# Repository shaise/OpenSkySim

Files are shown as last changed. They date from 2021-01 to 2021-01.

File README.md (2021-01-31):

# OpenSkySim
A wireless rc simulator controller

## Description
This open project aims to develop a small USB dongle that lets you use your FrSky transmitter as an RC simulator controller wirelessly. You only need to bind your transmitter to the dongle and start playing!  
This dongle supports both standard HID compatible simulators, AND PhoenixRC!  
The hardware is bases on STM32F103 microcontroller and TI CC2500 transceiver. The firmware is based on OpenSky FrSky-compatible receiver: https://github.com/fishpepper/OpenSky

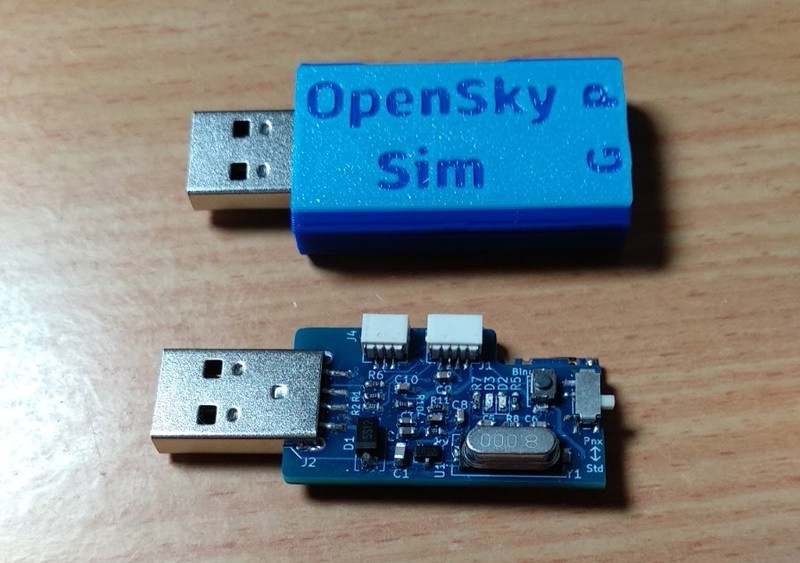
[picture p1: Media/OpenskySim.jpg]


## Assembling instructions

* Order the PCB by sending the [gerber files ](/Release/gerbers_frsim_2Layer_FR4.zip) to a manufacturer of your choice. I recommend [JLCPCB](https://jlcpcb.com/).
* Order all parts as listed in the [BOM](/Release/OpenSkySimBom.pdf) file. You will need a 0603 kit of resistors and capacitors, and for all other parts you will find a link in the BOM.
* Solder all parts. You can use the [Interactive BOM](https://htmlpreview.github.io/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) to assist you. 
* For the transmitter module, I used one without built in antenna, So if you are using the same module, you will need to add an antenna by soldering a 0.5mm transformer wire to the antenna pin, then trim the wire to a length of 31.5mm. (I tried one module with on board antenna but the reception was bad, If you find one that works, please let me know). Plese note: there are parts on both side of the PC
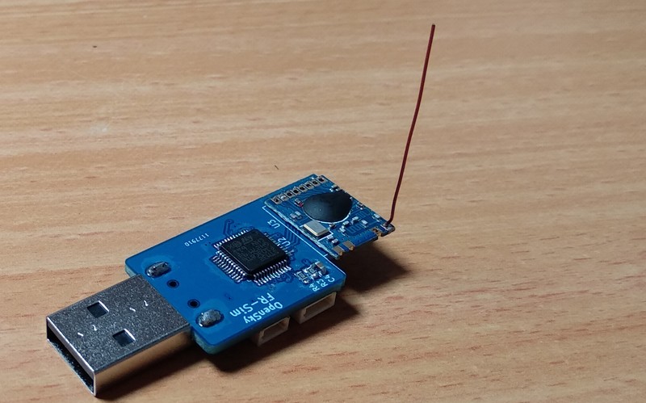
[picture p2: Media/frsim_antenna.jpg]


Top Side (click to enlarge):  
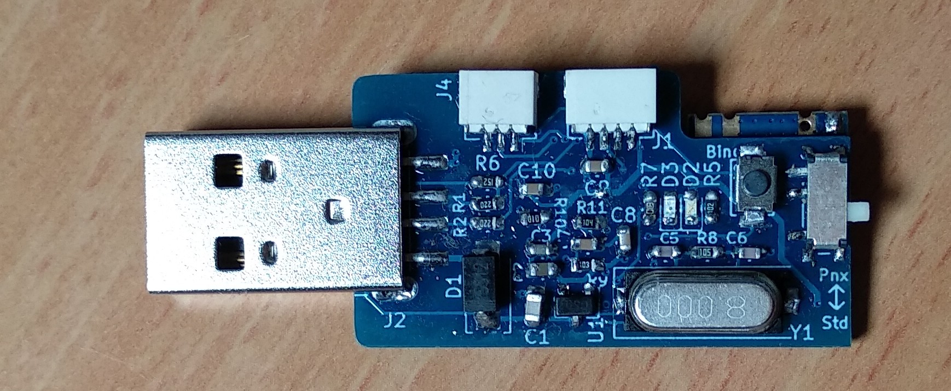
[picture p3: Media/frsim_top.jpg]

* If you have an access to a 3D printer you can print a plastic enclosure. Download and print the 2 stl files in the /Release folder. Use different color for the first 3 layers to get a nice text effect. 

## Programming the firmware
* You will need an ST-Link V2 compatible programmer and programming cable (links in the BOM)
* From the JST cable and Dupont connector kit prepare the programming cable as shown in the image (Note the colors!):
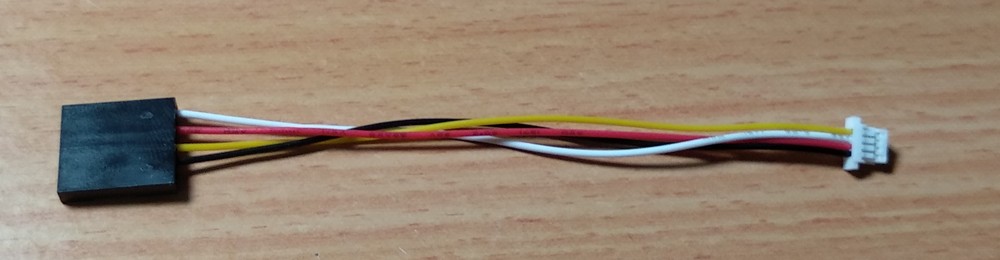
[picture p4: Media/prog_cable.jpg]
  

* Connect the cable between the programmer and dongle:  
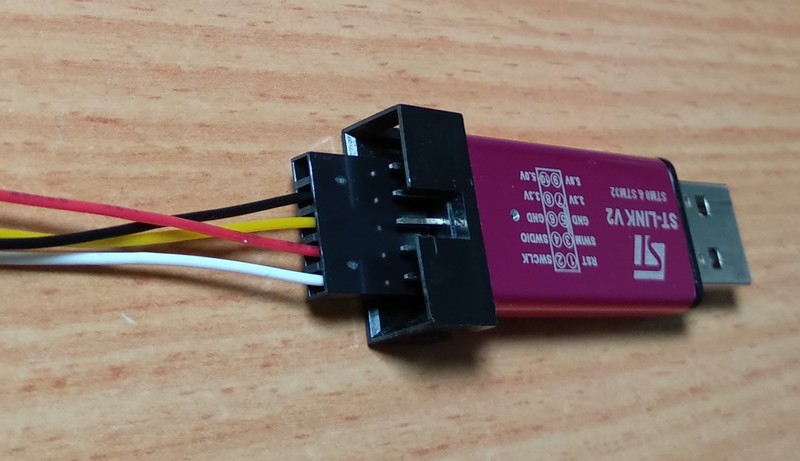
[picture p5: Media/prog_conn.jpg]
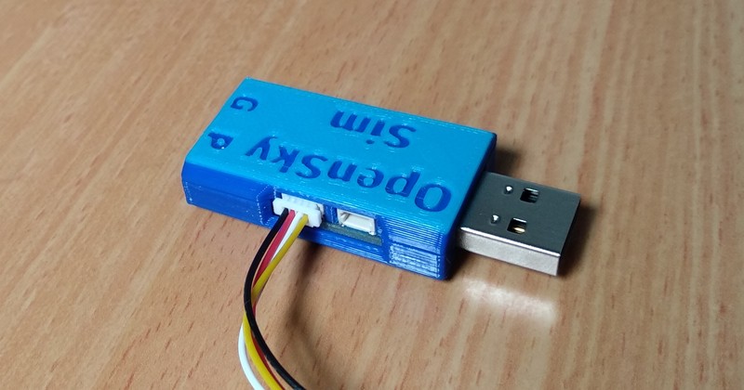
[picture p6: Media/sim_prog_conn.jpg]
  
* Connect the Stlink programmer to the PC. (no need to connect the dongle, it is powered from the programmer)
* Download the OpenSkySim firmware, and use a programming software such as the ST Link Utility and programm the dongle.  

## Usage
This dongle works with FR-Sky telemetry compatible transmitters. (SW 1 and 2 off on DJT modules)  
You first need to bind the dongle with the transmitter (this is a one-time operation, repeat only if you change transmitter):  
* Press and hold the bind button and insert the dongle to the PC. Wait for the green light to turn on.
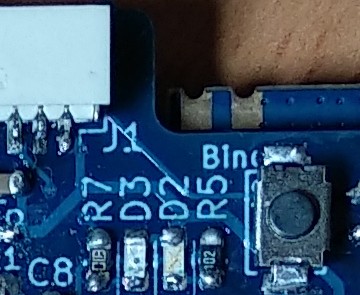
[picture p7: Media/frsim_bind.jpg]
 

* Start binding procedure in your transmitter. If you are using an external module such as the DJT, Press and hold the module bind button and turn on the transmitter. 
* Wait for the red led on the dongle to start blinking. When it does, binding is complete! Turn off the transmitter and pull the dongle out from the PC.  

From now on all you need to do to use the simulator is just by using the slide switch, select the operation mode: either 'Std' for standard HID compatible simulator or 'Pnx' for PhoenixRC, then insert the dongle to the PC and start Simm-ing!
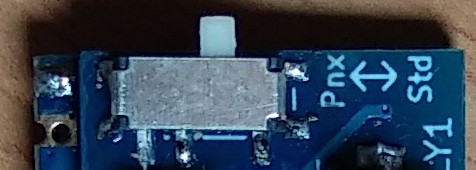
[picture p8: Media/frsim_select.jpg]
 

Remark: When using the dongle in 'Std' mode, the PC will recognize it as "OpenSky wireless sim dongle" HID game controller.

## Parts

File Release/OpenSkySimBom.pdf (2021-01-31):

Sheet1

Page 1

| Quantity | References | Value | Footprint | Sourced
1 | 6 | C3, C4, C7, C 100n_0603 | | Cap_0603
2 | 2 | C5, C6 | 20p_0603 | Cap_0603
3 | 1 | C2 | 22u_0603 | Cap_0603
4 | 1 | C1 | 4u7_0805_16V | Cap_0805
5 | 3 | R3, R4, R9 | 10K_0603 | Res_0603
6 | 2 | R1, R2 | 20R_0603 | Res_0603
7 | 2 | R5, R7 | 1K_0603 | Res_0603
8 | 2 | R10, R11 | 100K_0603 | Res_0603
9 | 1 | R6 | 1K5_0603 | Res_0603
10 | 1 | R8 | 1M_0603 | Res_0603
11 | 1 | D1 | SS110-A | Diode_SMA | https://www.aliexpress.com/item/4000331408791.html
12 | 1 | D2 | GREEN | LED_0603 | https://www.aliexpress.com/item/593098807.html
13 | 1 | D3 | RED | LED_0603 | https://www.aliexpress.com/item/593098807.html
14 | 1 | U3 | CC2500_MOD8_ANT | CC2500_MOD8_ANT | https://www.aliexpress.com/item/1005001408001275.html
15 | 1 | U2 | STM32F103C8Tx | LQFP-48_7x7mm_P0.5mm | https://www.aliexpress.com/item/10000399933096.html
16 | 1 | U1 | MCP1700 | SOT-23 | https://www.aliexpress.com/item/32995491794.html
17 | 1 | Y1 | 8Mhz | Crystal_SMD_HC49-SD | https://www.aliexpress.com/item/32844179609.html
18 | 1 | SW2 | SW_SPDT | SW_SPDT_PCM12 | https://www.aliexpress.com/item/32856542440.html
19 | 1 | SW1 | SW_BIND | SW_SPST_4x3 | https://www.aliexpress.com/item/1005001412157463.html
20 | 1 | J4 | JST1.0 | JST_SH_SM03B-SRSS-TB | https://www.aliexpress.com/item/32819231540.html
21 | 1 | J1 | Jst1.0x4 | JST_SH_SM04B-SRSS-TB | https://www.aliexpress.com/item/32819231540.html
22 | 1 | J2 | USB_B | USB_A_Horizontal | https://www.aliexpress.com/item/32826261577.html

Programmer and cable
1 | 1 | STLink V2 programmer | https://www.aliexpress.com/item/32867333890.html
2 | 1 | Jst 1.0 female conn + wire | https://www.aliexpress.com/item/1005001303141070.html
3 | 1 | 4 pin dupont female conn | https://www.aliexpress.com/item/33011610420.html

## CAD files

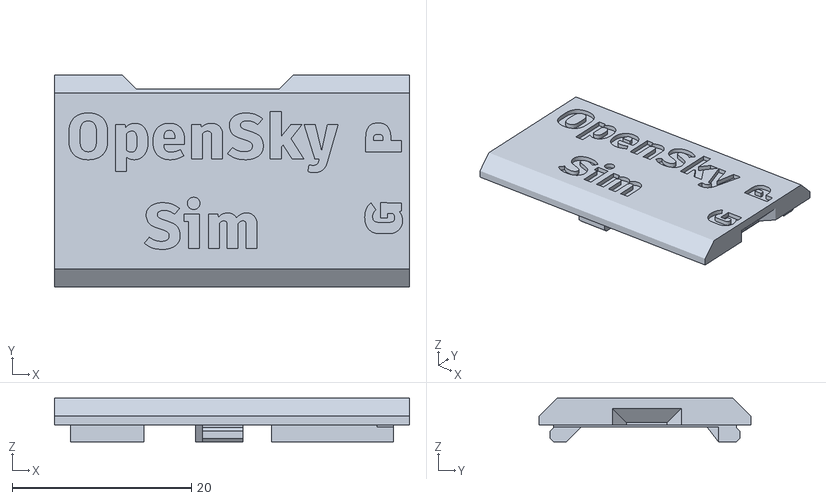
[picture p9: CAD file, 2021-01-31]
Release/SimTop.stl
39.6 x 23.6 x 4.90

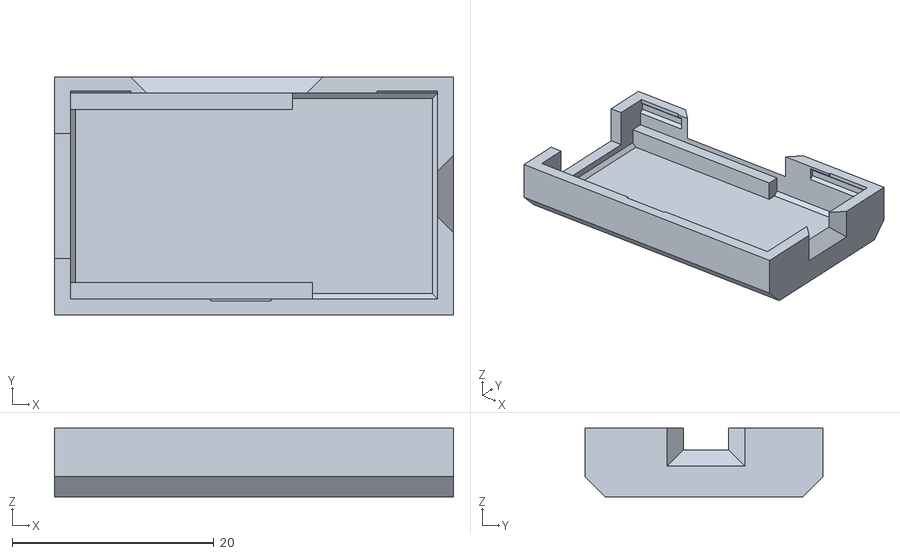
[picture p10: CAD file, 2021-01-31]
Release/SimBottom.stl
39.6 x 23.6 x 6.80

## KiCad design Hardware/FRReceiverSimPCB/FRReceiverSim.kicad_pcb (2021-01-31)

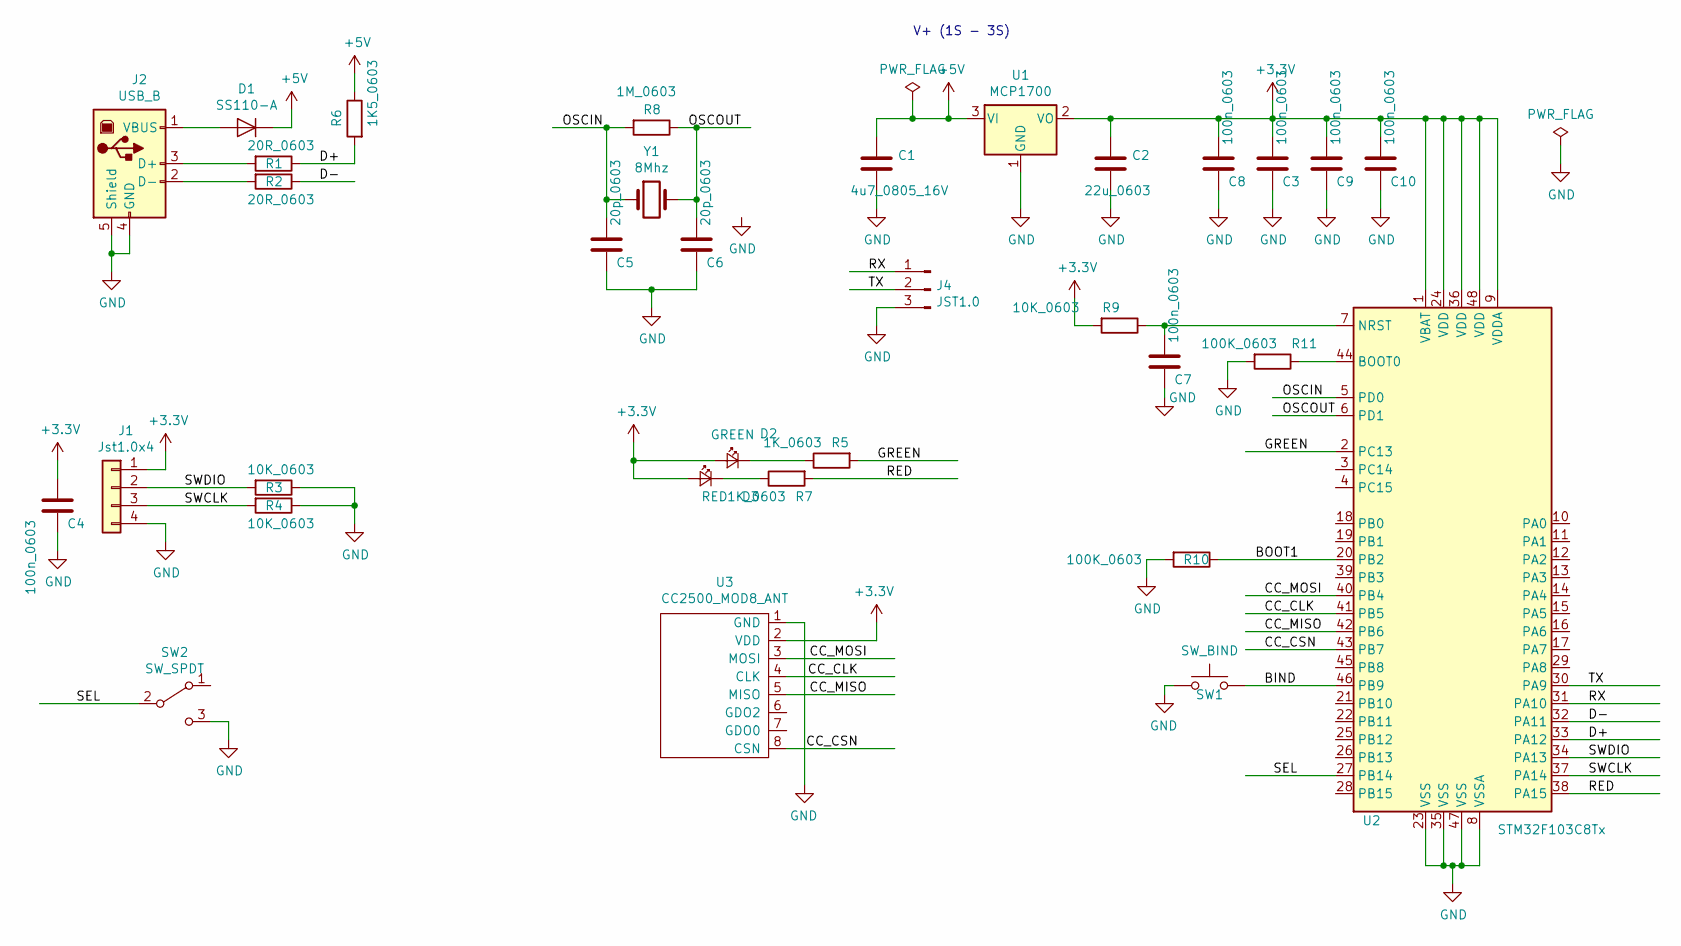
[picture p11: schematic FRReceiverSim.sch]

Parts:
C1: 4u7_0805_16V; C_0805_2012Metric
C2: 22u_0603; C_0603_1608Metric
C3, C4, C7, C8, C9, C10: 100n_0603; C_0603_1608Metric
C5, C6: 20p_0603; C_0603_1608Metric
D1: SS110-A; D_SMA
D2: GREEN; LED_0603_1608Metric
D3: RED; LED_0603_1608Metric
J1: Jst1.0x4; JST_SH_SM04B-SRSS-TB_1x04-1MP_P1.00mm_Horizontal
J2: USB_B; USB_A_CNCTech_1001-011-01101_Horizontal
J4: JST1.0; JST_SH_SM03B-SRSS-TB_1x03-1MP_P1.00mm_Horizontal
R1, R2: 20R_0603; R_0603_1608Metric
R3, R4, R9: 10K_0603; R_0603_1608Metric
R5, R7: 1K_0603; R_0603_1608Metric
R6: 1K5_0603; R_0603_1608Metric
R8: 1M_0603; R_0603_1608Metric
R10, R11: 100K_0603; R_0603_1608Metric
SW1: SW_BIND; SW_SPST_4x3
SW2: SW_SPDT; SW_SPDT_PCM12
U1: MCP1700; SOT-23
U2: STM32F103C8Tx; LQFP-48_7x7mm_P0.5mm
U3: CC2500_MOD8_ANT
Y1: 8Mhz; Crystal_SMD_HC49-SD

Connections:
+3V3: C2.1, C3.1, C4.1, C8.1, C9.1, C10.1, D2.2 (A), D3.2 (A), J1.1, R9.2, U1.2 (VO), U2.1 (VBAT), U2.9 (VDDA), U2.24 (VDD), U2.36 (VDD), U2.48 (VDD), U3.2 (VDD)
+5V: C1.1, D1.1 (K), R6.1, U1.3 (VI)
/BIND: SW1.1, U2.46 (PB9)
/BOOT1: R10.1, U2.20 (PB2)
/CC_CLK: U2.41 (PB5), U3.4 (CLK)
/CC_CSN: U2.43 (PB7), U3.8 (CSN)
/CC_MISO: U2.42 (PB6), U3.5 (MISO)
/CC_MOSI: U2.40 (PB4), U3.3 (MOSI)
/D+: R1.1, R6.2, U2.33 (PA12)
/D-: R2.1, U2.32 (PA11)
/GREEN: R5.2, U2.2 (PC13)
/OSCIN: C5.1, R8.2, U2.5 (PD0), Y1.1
/OSCOUT: C6.1, R8.1, U2.6 (PD1), Y1.2
/RED: R7.2, U2.38 (PA15)
/RX: J4.1, U2.31 (PA10)
/SEL: SW2.2 (B), U2.27 (PB14)
/SWCLK: J1.3, R4.2, U2.37 (PA14)
/SWDIO: J1.2, R3.2, U2.34 (PA13)
/TX: J4.2, U2.30 (PA9)
GND: C1.2, C2.2, C3.2, C4.2, C5.2, C6.2, C7.2, C8.2, C9.2, C10.2, J1.4, J2.4 (GND), J2.5 (Shield), J4.3, R3.1, R4.1, R10.2, R11.2, SW1.2, SW2.3 (C), U1.1 (GND), U2.8 (VSSA), U2.23 (VSS), U2.35 (VSS), U2.47 (VSS), U3.1 (GND)
unnamed: C7.1, R9.1, U2.7 (NRST)
unnamed: D1.2 (A), J2.1 (VBUS)
unnamed: D2.1 (K), R5.1
unnamed: D3.1 (K), R7.1
unnamed: J2.2 (D-), R2.2
unnamed: J2.3 (D+), R1.2
unnamed: R11.1, U2.44 (BOOT0)

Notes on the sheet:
V+ (1S - 3S)

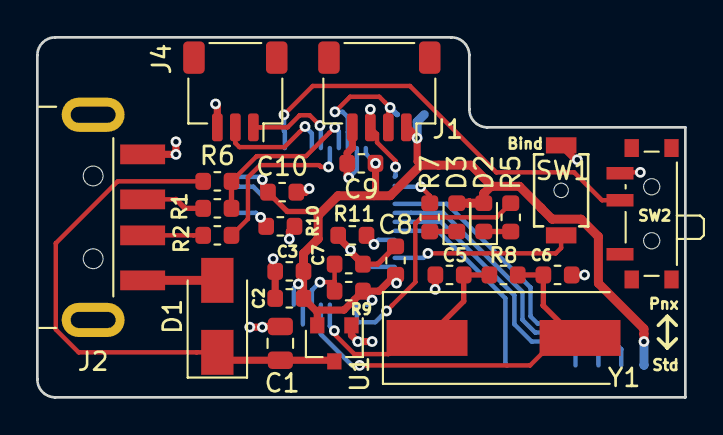
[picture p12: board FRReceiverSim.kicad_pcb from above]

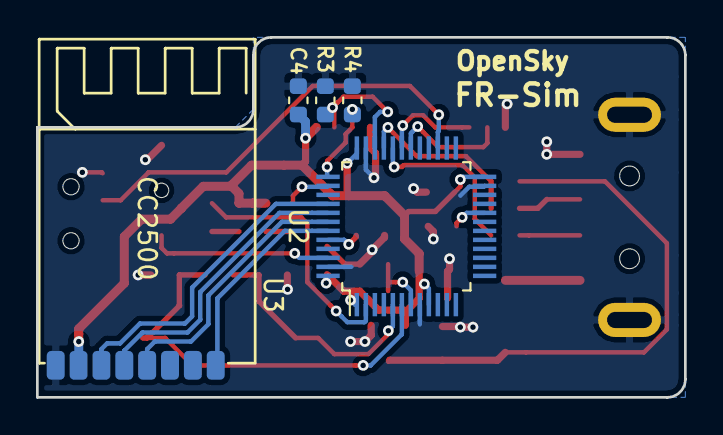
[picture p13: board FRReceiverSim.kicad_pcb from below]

Board: 2 copper layers, 36.0 x 20.0 mm, 33 parts (5 on the bottom side), 27 nets.

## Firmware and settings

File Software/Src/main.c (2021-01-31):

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
/* Includes ------------------------------------------------------------------*/
#include "main.h"
#include "usb_device.h"

/* USER CODE BEGIN Includes */
#include "stm32f1xx_it.h"
#include "stdio.h"
#include "debug.h"
#include "cc25xx.h"
#include "frsky.h"
#include "storage.h"
#include "io.h"
#include "usbd_customhid.h"

/* USER CODE END Includes */

TIM_HandleTypeDef htim3;
TIM_HandleTypeDef htim4;

UART_HandleTypeDef huart1;

/* USER CODE BEGIN PV */
typedef struct _simHID {
  uint8_t thr;
  uint8_t rud;
    uint8_t x;
    uint8_t y;
    uint8_t z;
    uint8_t slid;
    uint8_t btns;
} s_simHID;

typedef struct _simPnx {
    uint8_t ch1;
    uint8_t ch2;
    uint8_t ch3;
    uint8_t ch4;
    uint8_t ch5;
    uint8_t ch6;
    uint8_t ch7;
    uint8_t ch8;
} s_simPnx;

s_simHID reportSim;
s_simPnx reportPnx;

#define REPORT_SIM_SIZE 7
#define REPORT_PNX_SIZE 8

uint8_t PhoenixRCHash = 0;
uint8_t PhoenixRCRepCount = 0;
uint8_t is_phoenix = 1;

/* USER CODE END PV */

void SystemClock_Config(void);
static void MX_GPIO_Init(void);
static void MX_TIM4_Init(void);
static void MX_USART1_UART_Init(void);
static void MX_TIM3_Init(void);
/* USER CODE BEGIN PFP */
static void dwt_init(void);

/* USER CODE END PFP */

/**
  * @brief  The application entry point.
  * @retval int
  */
int main(void)
{
  /* MCU Configuration--------------------------------------------------------*/

  /* Reset of all peripherals, Initializes the Flash interface and the Systick. */
  HAL_Init();

  /* Configure the system clock */
  SystemClock_Config();

  /* Initialize all configured peripherals */
  MX_GPIO_Init();
  MX_TIM4_Init();
  MX_USART1_UART_Init();
  MX_USB_DEVICE_Init();
  MX_TIM3_Init();
  /* USER CODE BEGIN 2 */
  led_green_off();
  led_red_off();
  dwt_init();
  debug_init();
  cc25xx_init();
  storage_init();
  frsky_init();

  /* USER CODE END 2 */

  /* Infinite loop */
  /* USER CODE BEGIN WHILE */
  while (1)
  {
    /* USER CODE END WHILE */

    /* USER CODE BEGIN 3 */
	frsky_main();
  }
  /* USER CODE END 3 */
}

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
/* USER CODE BEGIN 4 */
static void dwt_init(void)
{
	CoreDebug->DEMCR |= CoreDebug_DEMCR_TRCENA_Msk;
    //DWT->LAR = 0xC5ACCE55;
    DWT->CYCCNT = 0;
    DWT->CTRL |= DWT_CTRL_CYCCNTENA_Msk;
}

#pragma GCC push_options
#pragma GCC optimize ("O3")
void delay_us(uint32_t us) {
	volatile uint32_t cycles = (SystemCoreClock/1000000L)*us;
	volatile uint32_t start = DWT->CYCCNT;
	do  {
	} while(DWT->CYCCNT - start < cycles);
}
#pragma GCC pop_options

uint8_t frsky_to_byte(uint16_t channel)
{
	// map frsky data to single byte
	// frsky seems to send us*1.5 (~1480...3020)
	// frsky span is 3020-1480  = 1540
	int val = channel - 1480;
	if (val < 0)
		val = 0;
	val = (val * 255) / 1540;
	if (val > 255)
		val = 255;
	return (uint8_t)val;
}

static void UpdatePhoenixHash()
{
  if (PhoenixRCRepCount > 0)
  {
    PhoenixRCRepCount--;
    if (PhoenixRCRepCount == 0)
      PhoenixRCHash = 0;
  }
}

static void hid_update_sim(uint16_t *channels)
{
  uint8_t ch7, ch8;
  reportSim.x = frsky_to_byte(channels[0]);
  reportSim.y = frsky_to_byte(channels[1]);
  reportSim.z = frsky_to_byte(channels[4]);
  reportSim.thr = frsky_to_byte(channels[2]);
  reportSim.rud = frsky_to_byte(channels[3]);
  reportSim.slid = frsky_to_byte(channels[5]);
  ch7 = frsky_to_byte(channels[6]);
  ch8 = frsky_to_byte(channels[7]);
  reportSim.btns = 0;
  if (ch7 > 196)
    reportSim.btns |= 1;
  else if (ch7 > 64)
    reportSim.btns |= 4;
  if (ch8 > 196)
    reportSim.btns |= 2;
  else if (ch8 > 64)
    reportSim.btns |= 8;

  USBD_CUSTOM_HID_SendReport(&hUsbDeviceFS, (uint8_t*)&reportSim, REPORT_SIM_SIZE);
}

static void hid_update_pnx(uint16_t *channels)
{
  reportPnx.ch1 = frsky_to_byte(channels[0]);
  reportPnx.ch2 = PhoenixRCHash;
  reportPnx.ch3 = frsky_to_byte(channels[1]);
  reportPnx.ch4 = frsky_to_byte(channels[2]);
  reportPnx.ch5 = frsky_to_byte(channels[3]);
  reportPnx.ch6 = frsky_to_byte(channels[4]);
  reportPnx.ch7 = frsky_to_byte(channels[5]);
  reportPnx.ch8 = 0x00;

  USBD_CUSTOM_HID_SendReport(&hUsbDeviceFS, (uint8_t*)&reportPnx, REPORT_PNX_SIZE);
}

void hid_update(uint16_t *channels)
{
  if (is_phoenix)
    hid_update_pnx(channels);
  else
    hid_update_sim(channels);
}

static void hid_update_sim_null(void)
{
  reportSim.x = 0x80;
  reportSim.y = 0x80;
  reportSim.z = 0x80;
  reportSim.thr = 0x00;
  reportSim.rud = 0x80;
  reportSim.slid = 0x80;
  reportSim.btns = 0;
  USBD_CUSTOM_HID_SendReport(&hUsbDeviceFS, (uint8_t*)&reportSim, REPORT_SIM_SIZE);
}

static void hid_update_pnx_null(void)
{
  UpdatePhoenixHash();
  reportPnx.ch1 = 0xff;
  reportPnx.ch2 = PhoenixRCHash;
  reportPnx.ch3 = 0xff;
  reportPnx.ch4 = 0xff;
  reportPnx.ch5 = 0xff;
  reportPnx.ch6 = 0x00;
  reportPnx.ch7 = 0x00;
  reportPnx.ch8 = 0x00;
  USBD_CUSTOM_HID_SendReport(&hUsbDeviceFS, (uint8_t*)&reportPnx, REPORT_PNX_SIZE);
}

void hid_update_null(void)
{
  if (is_phoenix)
    hid_update_pnx_null();
  else
    hid_update_sim_null();
}

void HandleSetReport(void)
{
  uint8_t i;
  uint8_t type;
  uint32_t sum;
  uint8_t *b;

  PhoenixRCHash = 0;
  USBD_CUSTOM_HID_HandleTypeDef *hhid = (USBD_CUSTOM_HID_HandleTypeDef *)hUsbDeviceFS.pClassData;
  b = hhid->Report_buf;

  // calculate phoenixrc hash
  type = b[2];
  if (type > 0)
    type--;
  type >>= 5;
  // 1. calculate sum
  switch (type) {
  case 0: sum = b[6]; break;
  case 1: sum = b[3]; break;
  case 2: sum = b[4] + b[5]; break;
  case 3: sum = b[1] + b[6]; break;
  case 4: sum = b[0] + b[7]; break;
  case 5: sum = b[5] + b[6]; break;
  case 6: sum = b[0] + b[1] + b[3] + b[4]; break;
  case 7:
    sum = 0;
    for(i = 0; i < 8; i++)
      if (i != 2)
        sum += b[i];
    break;
  }
  // 2. calc hash
  type &= 3;
  switch (type) {
  case 0: PhoenixRCHash = (uint8_t)(((sum * 8) & 0x7F) + 0x0D); break;
  case 1: PhoenixRCHash = (uint8_t)(((sum * 2) & 0x3F) + 0x12); break;
  case 2: PhoenixRCHash = (uint8_t)((((sum + 8) / 2) & 0x1F) + 0x10); break;
  case 3: PhoenixRCHash = (uint8_t)((((sum + 4) / 8) & 0xF) + 0x18); break;
  }
  PhoenixRCRepCount = 250;
}

/* USER CODE END 4 */
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


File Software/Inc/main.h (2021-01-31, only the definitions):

#define ONBOARD_LED_Pin GPIO_PIN_13
#define ONBOARD_LED_GPIO_Port GPIOC
#define PNX_SEL_Pin GPIO_PIN_14
#define PNX_SEL_GPIO_Port GPIOB
#define RED_LED_Pin GPIO_PIN_15
#define RED_LED_GPIO_Port GPIOA
#define CC2500_MOSI_Pin GPIO_PIN_4
#define CC2500_MOSI_GPIO_Port GPIOB
#define CC2500_CLK_Pin GPIO_PIN_5
#define CC2500_CLK_GPIO_Port GPIOB
#define CC2500_MISO_Pin GPIO_PIN_6
#define CC2500_MISO_GPIO_Port GPIOB
#define CC2500_CSN_Pin GPIO_PIN_7
#define CC2500_CSN_GPIO_Port GPIOB
#define BIND_Pin GPIO_PIN_9
#define BIND_GPIO_Port GPIOB
#define DEBUG 1
#define FAILSAFE_PRESS_TIME 50   // 5 seconds
#define FAILSAFE_PROGRAM_WAIT_TIME 100   // 10 seconds
#define DEFAULT_FSCAL_VALUE -62

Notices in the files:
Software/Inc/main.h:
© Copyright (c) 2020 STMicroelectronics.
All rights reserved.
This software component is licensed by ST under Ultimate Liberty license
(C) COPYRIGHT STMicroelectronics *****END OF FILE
